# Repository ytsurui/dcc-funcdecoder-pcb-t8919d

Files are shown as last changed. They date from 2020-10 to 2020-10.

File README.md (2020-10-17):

# DCC Function Decoder PCB Data for TOMIX 8919

NMRA規格の信号を受信して動作する、ファンクション専用のDCCデコーダの基板設計データです。

TOMIX製Nゲージ鉄道模型に搭載されている、8919と刻印されている基板と交換してそのまま搭載可能な設計となっております。

回路図、基板設計データ、面付け済みの設計データを含みます。
<br>面付け済みのデータについては、ガーバーデータも含みます。 (elecrowにて製造できることを確認済み)

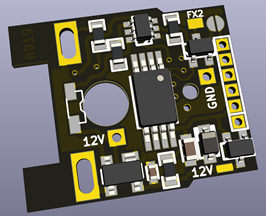
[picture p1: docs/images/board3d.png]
PCB 3D Preview


## 取り扱い上の注意点

  * 基板設計ミスがあるため、現在の設計データのまま製造した場合、取付穴径を3.8mm程度に開けなおす必要があります。<br>この問題点はRev.1以降のリリースで修正予定です。

### 主要スペック
  * 組み立て後の基板サイズ: 17.5mm x 14.5mm x 2.6mm
  * TOMIX製Nゲージ鉄道模型に搭載されている、8919と刻印されている基板と差し替えて取り付け可能
  * 基板表面にヘッドライト用、裏面にテールライト用のLEDを実装可能<br>(LEDは面実装タイプ)
  * MOSFETを追加で実装することで、追加のファンクションを1つ配線可能
  * ヘッドライトとテールライトの回路については、定電流回路を搭載し、一定の照度でLEDを点灯可能
  * マイコンプログラム書き込み用端子を装備し、ピンヘッダを使用した簡単な治具でAVRライタと接続し、ファームウェアを変更可能

### 対応するファームウェア
  * [Atmel ATtiny45 DCC Function Decoder Firmware](https://github.com/ytsurui/dcc-funcdecoder-firmware)

### 各種ドキュメント

  * [パーツリスト](docs/partslist.md)

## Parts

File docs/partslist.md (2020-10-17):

# Parts List

<table>
  <tr>
    <td>Reference</td>
    <td>Name</td>
    <td>Package</td>
    <td>Count</td>
    <td>Shop Links</td>
  </tr>
  <tr>
    <td>U1</td>
    <td>ATTiny45-20XUR</td>
    <td>TSSOP-8</td>
    <td>1</td>
    <td><a href="https://www.digikey.jp/product-detail/ja/microchip-technology/ATTINY45-20XUR/ATTINY45-20XURCT-ND/2774364">Digikey (ja)</a><br />
    <a href="https://www.digikey.jp/product-detail/en/microchip-technology/ATTINY45-20XUR/ATTINY45-20XURCT-ND/2774364">Digikey (en)</a></td>
  </tr>
  <tr>
    <td>D1</td>
    <td>BAS3007A-RPP</td>
    <td>SOT-143</td>
    <td>1</td>
    <td><a href="https://www.digikey.jp/product-detail/ja/infineon-technologies/BAS3007ARPPE6327HTSA1/BAS3007ARPPE6327HTSA1CT-ND/2023144">Digikey (ja)</a><br />
    <a href="https://www.digikey.jp/product-detail/en/infineon-technologies/BAS3007ARPPE6327HTSA1/BAS3007ARPPE6327HTSA1CT-ND/2023144">Digikey (en)</a></td>
  </tr>
  <tr>
    <td>D2</td>
    <td>UDZV5.1B</td>
    <td>SOD-323</td>
    <td>1</td>
    <td><a href="https://www.digikey.jp/product-detail/ja/rohm-semiconductor/UDZVTE-175-1B/UDZVTE-175-1BCT-ND/4571455">Digikey (ja)</a><br />
    <a href="https://www.digikey.jp/product-detail/en/rohm-semiconductor/UDZVTE-175-1B/UDZVTE-175-1BCT-ND/4571455">Digikey (en)</a><br />
    <a href="https://akizukidenshi.com/catalog/g/gI-07434/">秋月電子通商</a></td>
  </tr>
  <tr>
    <td>Q1</td>
    <td>2SC4116-GR</td>
    <td>SC-70</td>
    <td>1</td>
    <td><a href="https://www.digikey.jp/product-detail/ja/toshiba-semiconductor-and-storage/2SC4116-GR-LF/2SC4116-GRLFCT-ND/3191333">Digikey (ja)</a><br />
    <a href="https://www.digikey.jp/product-detail/en/toshiba-semiconductor-and-storage/2SC4116-GR-LF/2SC4116-GRLFCT-ND/3191333">Digikey (en)</a><br />
    <a href="https://akizukidenshi.com/catalog/g/gI-02705/">秋月電子通商</a></td>
  </tr>
  <tr>
    <td>Q2</td>
    <td>2N7002DW
    <br />SSM6N7002BFU</td>
    <td>SOT-363</td>
    <td>1 (Optional)</td>
    <td><a href="https://www.digikey.jp/product-detail/ja/diodes-incorporated/2N7002DW-7-F/2N7002DW-FDICT-ND/750003">Digikey (ja)</a><br />
    <a href="https://www.digikey.jp/product-detail/en/diodes-incorporated/2N7002DW-7-F/2N7002DW-FDICT-ND/750003">Digikey (en)</a><br />
    <a href="https://akizukidenshi.com/catalog/g/gI-05999/">秋月電子通商</a><br />
    <a href="https://akizukidenshi.com/catalog/g/gI-08465/">秋月電子通商 (互換品)</a></td>
  </tr>
  <tr>
    <td>Q3</td>
    <td>SSM3K7002BFU<br>SSM3K7002CFU</td>
    <td>SC-70</td>
    <td>1</td>
    <td><a href="https://www.digikey.jp/product-detail/ja/toshiba-semiconductor-and-storage/SSM3K7002CFU-LF/SSM3K7002CFULFCT-ND/5403475">Digikey (ja)</a><br />
    <a href="https://www.digikey.jp/product-detail/en/toshiba-semiconductor-and-storage/SSM3K7002CFU-LF/SSM3K7002CFULFCT-ND/5403475">Digikey (en)</a><br />
    <a href="https://akizukidenshi.com/catalog/g/gI-08576/">秋月電子通商</a></td>
  </tr>
  <tr>
    <td>C1</td>
	  <td>0.1uF 25V 1005</td>
	  <td>1.0mm x 0.5mm</td>
	  <td>1</td>
    <td><a href="https://www.digikey.jp/product-detail/ja/murata-electronics/GRM155R71H104KE14J/490-13342-1-ND/5973352">Digikey (ja)</a><br />
    <a href="https://www.digikey.jp/product-detail/en/murata-electronics/GRM155R71H104KE14J/490-13342-1-ND/5973352">Digikey (en)</a><br />
    <a href="https://akizukidenshi.com/catalog/g/gP-13377/">秋月電子通商</a></td>
  </tr>
  <tr>
    <td>C2</td>
    <td>22uF 6.3V 1608</td>
    <td>1.6mm x 0.8mm</td>
    <td>1</td>
    <td><a href="https://www.digikey.jp/product-detail/ja/murata-electronics/GRM188R60J226MEA0D/490-7611-1-ND/4280544">Digikey (ja)</a><br />
    <a href="https://www.digikey.jp/product-detail/en/murata-electronics/GRM188R60J226MEA0D/490-7611-1-ND/4280544">Digikey (en)</a><br />
    <a href="https://akizukidenshi.com/catalog/g/gP-08062/">秋月電子通商</a></td>
  </tr>
  <tr>
    <td>R1</td>
    <td>4.7kohm 1/10W 1608</td>
    <td>1.6mm x 0.8mm</td>
    <td>1</td>
    <td><a href="https://www.digikey.jp/products/ja/resistors/chip-resistor-surface-mount/52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">Digikey (ja)</a><br />
    <a href="https://www.digikey.jp/products/en/resistors/chip-resistor-surface-mount/52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">Digikey (en)</a><br />
    <a href="https://akizukidenshi.com/catalog/g/gR-14121/">秋月電子通商</a></td>
  </tr>
  <tr>
    <td>R2</td>
    <td>100kohm 1/10W 1608</td>
    <td>1.6mm x 0.8mm</td>
    <td>1</td>
    <td><a href="https://www.digikey.jp/products/ja/resistors/chip-resistor-surface-mount/52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">Digikey (ja)</a><br />
    <a href="https://www.digikey.jp/products/en/resistors/chip-resistor-surface-mount/52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">Digikey (en)</a><br />
    <a href="https://akizukidenshi.com/catalog/g/gR-15321/">秋月電子通商</a></td>
  </tr>
  <tr>
    <td>R3, R4</td>
    <td>150ohm 1/10W 1608</td>
    <td>1.6mm x 0.8mm</td>
    <td>2</td>
    <td><a href="https://www.digikey.jp/products/ja/resistors/chip-resistor-surface-mount/52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">Digikey (ja)</a><br />
    <a href="https://www.digikey.jp/products/en/resistors/chip-resistor-surface-mount/52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">Digikey (en)</a><br />
    <a href="https://akizukidenshi.com/catalog/g/gR-06151/">秋月電子通商</a></td>
  </tr>
</table>

---

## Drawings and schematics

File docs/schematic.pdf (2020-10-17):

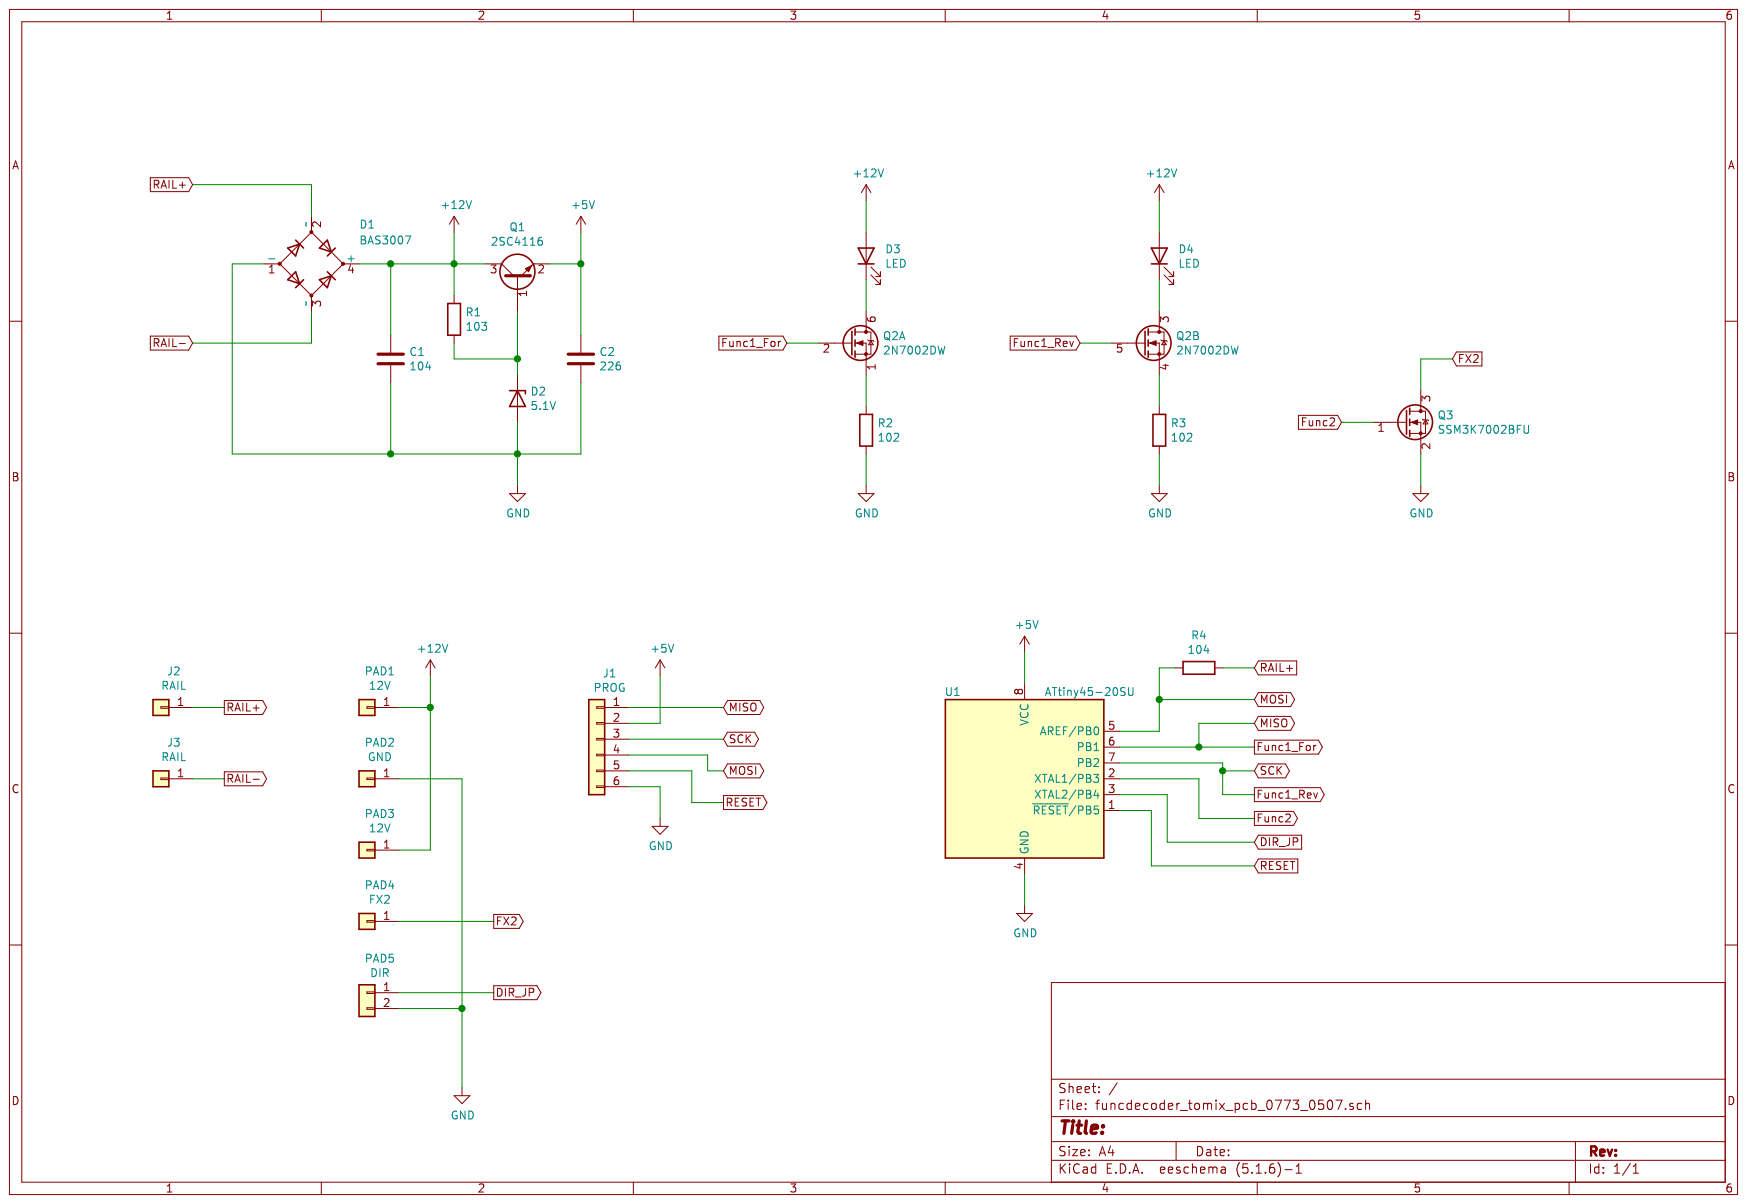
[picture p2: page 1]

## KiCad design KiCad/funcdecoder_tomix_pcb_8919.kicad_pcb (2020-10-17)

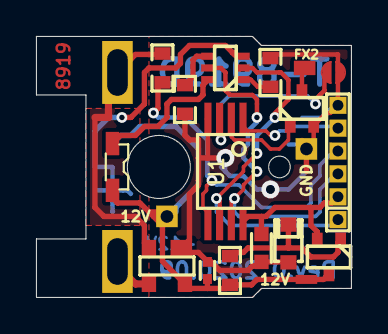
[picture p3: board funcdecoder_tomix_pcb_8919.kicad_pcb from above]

Board: 2 copper layers, 17.5 x 14.5 mm, 24 parts (1 on the bottom side), 17 nets.

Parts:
C1: 104; C_1005
C2: 226; C_1608
D1: BAS3007; SOT-143
D2: 5.1V; UMD2
D3, D4: LED; LED_1224_SIDE
H**: HOLE_1.2mm
H**#2: HOLE_3.5mm
J1: PROG; PAD_PROG_6PIN_HOLE0.6
J2, J3: RAIL; TOMIX_CONTACT_HOLE
PAD1: 12V; PAD_1.2x1.2_Hole0.7
PAD2: GND; PAD_1.2x1.2_Hole0.7
PAD3: 12V; PAD_0.5x1.2_SMD
PAD4: FX2; PAD_1.2x0.8_SMD
PAD5: DIR; SOLDER_CONN_PAD_1.5mm
Q1: 2SC4116; SC-70
Q2: 2N7002DW; SOT-363-nomark
Q3: SSM3K7002BFU; SC-70
R1: 103; R_1608
R2, R3: 102; R_1608
R4: 104; R_1608
U1: ATtiny45-20SU; TSSOP-8

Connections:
+5V: C2.1, J1.2, Q1.2, U1.8
+12V: C1.1, D1.4, D3.2, D4.2, PAD1.1, PAD3.1, Q1.3, R1.1
DIR_JP: PAD5.1, U1.3
FX2: PAD4.1, Q3.3
Func1_For: J1.1, Q2.2, U1.6
Func1_Rev: J1.3, Q2.5, U1.7
Func2: Q3.1, U1.2
GND: C1.2, C2.2, D1.1, D2.2, J1.6, PAD2.1, PAD5.2, Q3.2, R2.2, R3.2, U1.4
MOSI: J1.4, R4.2, U1.5
unnamed: D2.1, Q1.1, R1.2
unnamed: D3.1, Q2.6
unnamed: D4.1, Q2.3
unnamed: Q2.1, R2.1
unnamed: Q2.4, R3.1
RAIL+: D1.2, J2.1, R4.1
RAIL-: D1.3, J3.1
RESET: J1.5, U1.1
